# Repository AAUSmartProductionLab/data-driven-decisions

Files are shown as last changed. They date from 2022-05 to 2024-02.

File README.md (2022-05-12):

# IIoT Box Start-up guide

This guide will describe the step-by-step process to set up the IIoT Box on the shopfloor.

## Initial Steps

   1. Power up the box using the USB-A to USB-A cable provided in the box.
   2. Connect to the WiFi Access Point with that has the same name as the IIoT Box (e.g. iiot_box_2).
   3. Once connected, the status of the raspberry pi can be check visiting: `10.3.141.1` in the browser. The credentials are: **username: iiot_case_2** and **password: robotlab**. From the dashboard it can be seen what devices are connected to the IIoT Box this could for example be the sensor boxes. These will appear with the host name ESP followed by a 6 number/letter ID e.g. **ESPBox1** or **ESPBox2**.
   4. If everything is up and running (see: [Troubleshooting](TROUBLESHOOTING.md)) Node-RED can be accessed through port 1880. So go to the address `10.3.141.1:1880` in the browser.
   5. In Node-RED data can be accessed, analyzed and formatted such that it can be used in a dashboard or for storing. For a more in depth guide on Node-RED check the guide here (see: [Node-RED Guide](node-red/README.md)).

---

## Contents of the IIoT Box

The IIoT box contains a Raspberry Pi 3B/3B+ that is used for setting up the access point and for storing the data from the sensor boxes. The IIoT box comes a 7-inch touch display, which can be used for debugging and visualization purposes. The IIoT box also comes with two sensor boxes. These sensor boxes uses a Wemos D1 Mini Pro ESP8266 microcontroller for collection and sending of data from the sensors. The exact sensors and their respective datasheets can be found in the folder [Sensor Descriptions and Datasheets](sensors/README.md).

---

## Usernames and Passwords

| | IIoT_Box_1  | IIoT_Box_2  | IIoT_Box_3  | IIoT_Box_4  |
|---|---|---|---|---|
| Username | pi | pi | pi | pi |
| Password | robotlab | robotlab | robotlab | robotlab |
| SSID(WiFi Name) | iiot_case_1 | iiot_case_2 | iiot_case_3 | iiot_case_4 |
| WiFi Password | robotlab | robotlab | robotlab | robotlab |
| Raspap username | admin | admin | admin | admin |
| Raspap password | robotlab | robotlab | robotlab | robotlab |

---

## More Guides and Descriptions

- [Node-RED Guide](node-red/README.md)
- [Communication and Electrical Diagrams](diagrams/README.md)
- [Sensor Descriptions and Datasheets](sensors/README.md)
- [Troubleshooting](TROUBLESHOOTING.md)
- [Code](code/README.md)

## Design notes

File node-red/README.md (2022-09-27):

# Node-RED Guide

This is a guide on how to use and understand the currently implemented Node-RED flows. This guide will only go through the basics briefly, so it is suggested to watch this YouTube guide to get a better understanding of Node-RED (see: [Video-Guide](https://www.youtube.com/watch?v=3AR432bguOY&ab_channel=OptoVideo)).

## The Basics

Node-RED is a flowbased programming tool developed by IBM and is often times used to interface different programs and APIs with eachother. This feature is very useful, in the context of IoT and IIoT, since there are often many different devices that operate with different programming languages, interfaces and programs. Node-RED can then act as the glue tying all these technologies together. The programs made in Node-RED are known as **flows** and these **flows** consist of **nodes** that are essentially programming blocks that have different functionalities. The **nodes** usually have an input, output or both and can be chained together to give a desired output.

Node-RED is accessed through a webinterface that is usually located on port `1880`. This means that if you type the IP-address of the device, running Node-RED, into the URL field in the browser followed by `:1880` it should open Node-RED. An example of this can be seen in the Figure 1.

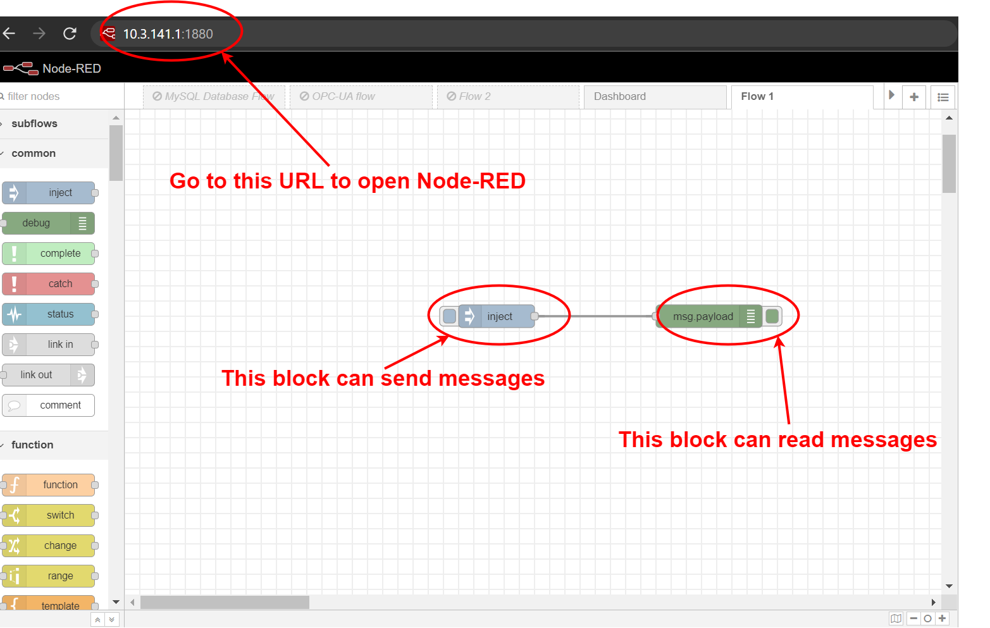
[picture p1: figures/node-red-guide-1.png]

*Figure 1: Node-RED example flow*

Two of the most essential programming blocks can also be seen in the Figure 1. The **inject** node and the **debug** node. The **inject** node is used to send messages, timestamps or to trigger other nodes. The **debug** node is used to read messages from different parts of the flow.

Node-RED has many basic nodes for message manipulation, these nodes can sort, join and split messages. Other nodes are related to connectivity such as MQTT, TCP, UDP and HTTP built in. In the IIoT boxes the primary communication protocol used is MQTT, that is often used together with various IoT devices such as ESP32.

## The IIoT Box Flow

The IIoT Boxes currently has two flows implemented in Node-RED. Firstly, there is a data collection flow that sends the data from the sensors on the ESP Boxes into a localized database in the IIoT Box. Secondly, there is a visualization flow that is used to show an example of a dashboard that can be made from the data stored in the database.

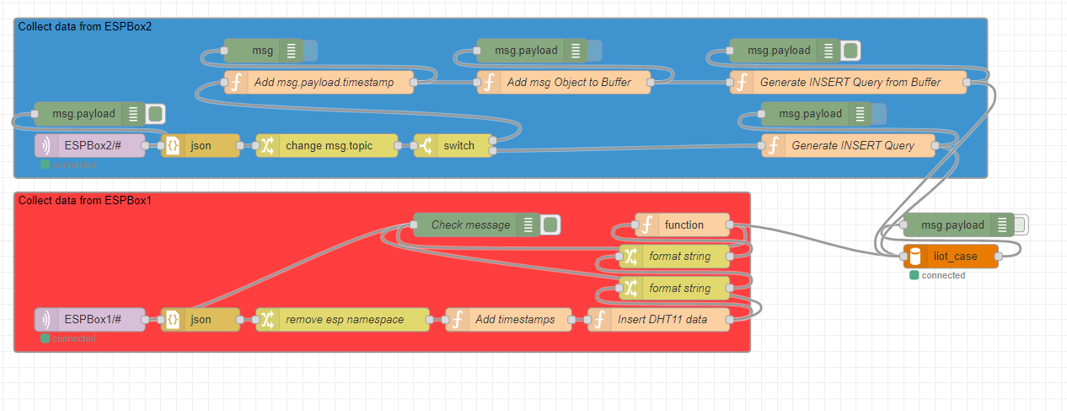
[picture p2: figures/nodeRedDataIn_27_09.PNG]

*Figure 2: The Node-RED Data Insert Flow as of 27/09/2022.*

As shown in Figure 2., there are currently (27/09/2022) two data insert pathways; one for each ESP-box. The ESPBox1 flow concerns the DHT11 data, the ESPBox2 flow concerns the IMU and Line Tracker. The DHT11 sensor document must be parsed and correct timestamps applied, as the ESPs do not have the correct time. The resulting records are then entered into the database. A buffer is implemented for the IMU sensor data, due to the high sample rate of this sensor (50ms). The other ESPBox2 data values are entered into the relevant tables in the database based on their topic (tracker, tracker2, etc.).

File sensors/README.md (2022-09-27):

# Sensors
Several sensor options have been implemented, descriptions of which can be found below. The sensors that have currently (11/07/2022) been 
implemented are:

- Diffuse/Reflective Optosensor
- DHT11
- IMU

### Optosensor
The selected optosensor can be ustilised in either diffuse- or reflective-mode (diffuse-mode is default). In the former implemen-
-tation, the sensor functions as a normally open (NO) contact, and as a normally closed (NC) in the latter. In order to switch
modes, it is necessary to alter the sensing circuit configuration, to reconfigure the Node-RED flows and also to make use of re-
-flective material. It is advised that this reconfiguration be carried out by or in collaboration with the Lab Engineers or an-
-other, qualified person.

##### Code Function
The code for the Optosensor makes use of a state machine to monitor the status of the sensor relative to previous statuses. If no
 object is detected by the sensor, and no object has been previously detected, a '0' status is returned. If an object is then de-
 -tected, a '1' status is returned. If this object remains for a period of time, that is, continues to be detected, then a '2' 
 status is returned. When the object finally ceases to be detected, a '3' status is returned. This modality is inverted when the 
 sensor is configured in reflective-mode. The following table should serve to clarify:
 
| **Condition** | **Previous Condition** | **Diffuse-Mode** | **Reflective-Mode** |
|---|---|---|---|
| No Object | No Object | 0 | 2 |
| Object | No Object | 1 | 3 |
| Object | Object | 2 | 0 |
| No Object | Object | 3 | 1 |

The sensor condition is sampled on a 200ms basis as default, but this time can be successfully reduced to 50ms for fast moving sys-
-tems. Currently (27/09/2022), only 1 and 0 values are sent on to Node-RED. 

### DHT11
The DHT11 sensor is used to sample ambient temperature and humidity in an area. This sensor provides a humidity sensing range of 
20-80% with an accuracy of ±5%, and a temperature sensing range of 0-50°C with an accuracy of ±2°C. The sample rate is max 1Hz. 

##### Code Implementation
The current (11/07/2022) code implementation samples the temperature and humidity every 5 minutes, stores this data as a JSON-document 
on the ESP-box until 6 samples have been collected. This JSON-document is then published to the MQTT topic ESPBox1/DHT11. 

### IMU
The IMU sensor is used to gather acceleration and rotation data. An MPU6050 is currently (27/09/2022) used for this sensor. 

##### Code Implementation
The current (27/09/2022) code implementation samples the IMU data every 50ms and publishes this data immediately to the MQTT topic 
ESPBox2/imu.

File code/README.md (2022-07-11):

# Code
In this directory, the various code pieces that are used by the Raspberry Pi and the ESP-boxes can be found.
The contents of each folder are:

- **cpp:** This folder contains cpp-files for each ESP-box (1 & 2), they have been developed with PlatformIO using the Arduino framework.
           There is also a folder condtaining code for a wiegand-based RFID-reader.
- **node-red:** This folder contains JSON-files for the exported flows from Node-RED running on the Raspberry Pi. The currently hosted
            flows include:
            - Data Input
            - Dashboard
            - Datalog Download
- **python:** This folder contains a python script which governs the display for the Raspberry Pi touch-screen, as well as .png-files for
           this.

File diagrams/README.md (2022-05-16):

# Technical Documentation
Here is the documentation for the IIoT Box and the ESP Boxes

## Electrical Diagrams
Below you can see diagrams of the two ESP Box types. These show the connections between the various components and the requisite 
voltage levels to assist in troubleshooting of the ESP Boxes. 

### ESP Box Type 01
The Type 01 ESP Box has both an RFID reader and DHT11 connected, which are supplied separately via the 5V and 3.3V pins on the ESP.
This type utilises the ESP's built-in DeepSleep functionality, which requires that the RST pin be connected to the D0 pin, in order 
for the ESP to wake-up without external intervention. Below can be seen the electrical diagram for the Type 01 ESP Box.

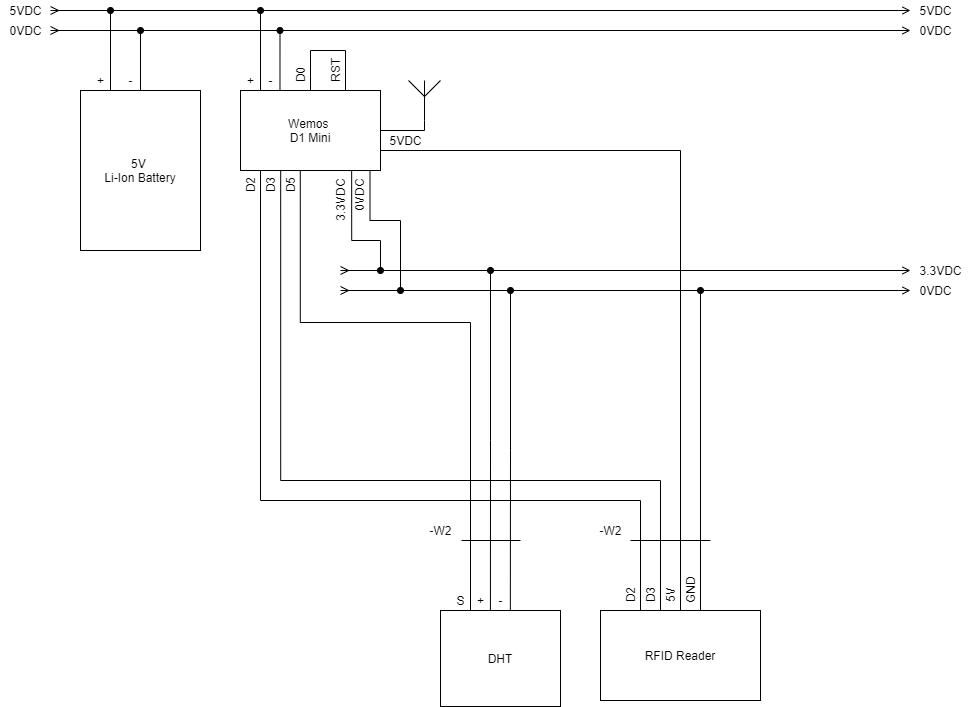
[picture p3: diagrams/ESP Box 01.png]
Electrical Diagram of the ESP Box Type 01


The below table summarises the pin connections for the Type 01:

| ESP Pin | Conductor Colour | Target | Comment |
|---|---|---|---|
| D0 | --- | RST |  Function not currently used |
| Tx | | Tx (RFID)  | |
| Rx | | Rx (RFID)  | |
| 5V | Red | Vcc (RFID) | |
| GND | Black | GND | |
| D5 | Blue | S (DHT11)  | |
| 3.3V | Red | + (DHT11)  | |
| GND | Black | - (DHT11)  | |

### ESP Box Type 02
The Type 02 ESP Box has an IMU and an industrial diffuse/through-beam PNP-type optosensor connected, which are supplied separately 
via the 3.3V and 5V pins on the ESP. The optosensor is supplied 12V via a 5V/12V Boost Regulator. This type does not utilise the 
ESP's built-in DeepSleep functionality. Below can be seen the electrical diagram for the Type 02 ESP Box.

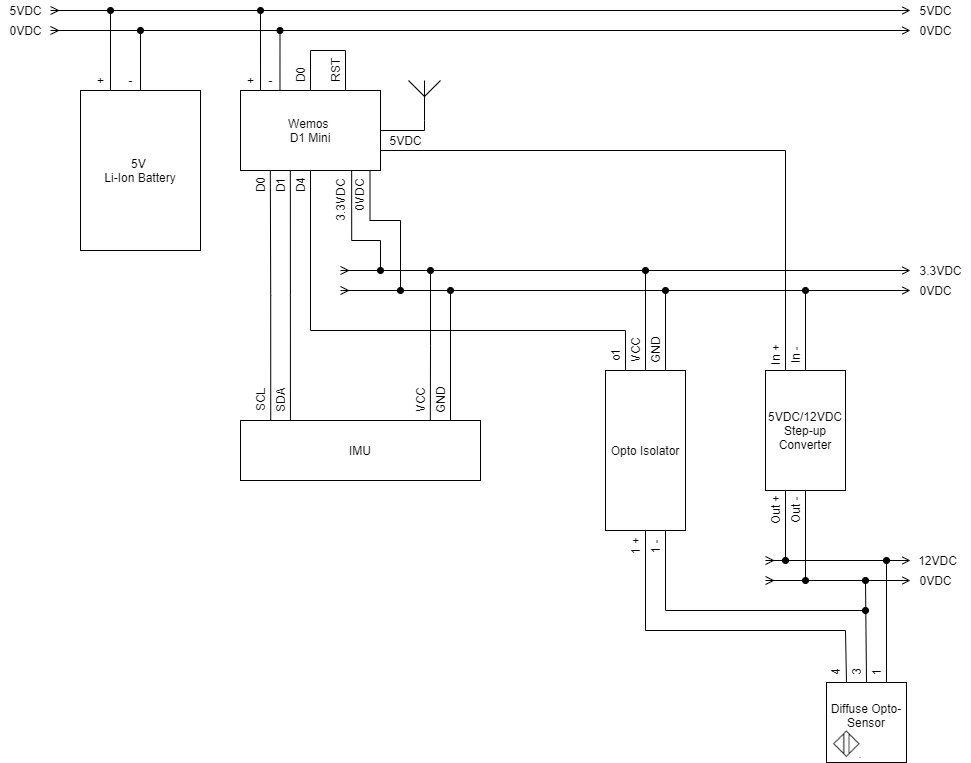
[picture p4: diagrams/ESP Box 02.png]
Electrical Diagram of the ESP Box Type 02


The below table summarises the pin connections for the Type 02:

| ESP Pin | Conductor Colour | Target | Comment |
|---|---|---|---|
| D0 | Green | SCL (IMU) | |
| D1 | Blue | SDA (IMU) | |
| 3.3 | Red | Vcc (IMU) | |
| GND | Black | GND (IMU) | |
| D4 | White | o1 (Optoisolator) | |
| 3.3V | Red | Vcc (Optoisolator) | |
| GND | Black | GND (Optoisolator) | |
| 5V | Red | In+ (5V/12V Step-up) | |
| GND | Black | In- (5V/12V Step-up) | |

Furthermore, the pin connections for the optoisolator board are summmarised below:

| Optoisolator Pin | Conductor Colour | Target | Comment |
|---|---|---|---|
| 1+ | Black | Pin 4 (Optosensor) | |
| 1- | Blue | Pin 3 (Optosensor)/ GND (5V/12V Step-up) | |
| 2+ | Brown | Pin 2 (Optosensor) | Function currently not in use (can be connected) |

Finally, the pin connections for the Boost Regulator are summarised below:

| 5V/12V Step-up Converter Pin | Conductor Colour | Target | Comment |
|---|---|---|---|
| In+ | Red | 5V (ESP) | |
| In- | Black | GND (ESP) | |
| Out+ | White | Pin 1 (Optosensor) | |
| Out- | Blue | Pin 3 (Optosensor)/ 1- (Optoisolator) | |

## Communication Diagrams
The below diagram illustrates the data flow from sensors to user, to assist in troubleshooting data-collection
issues. 

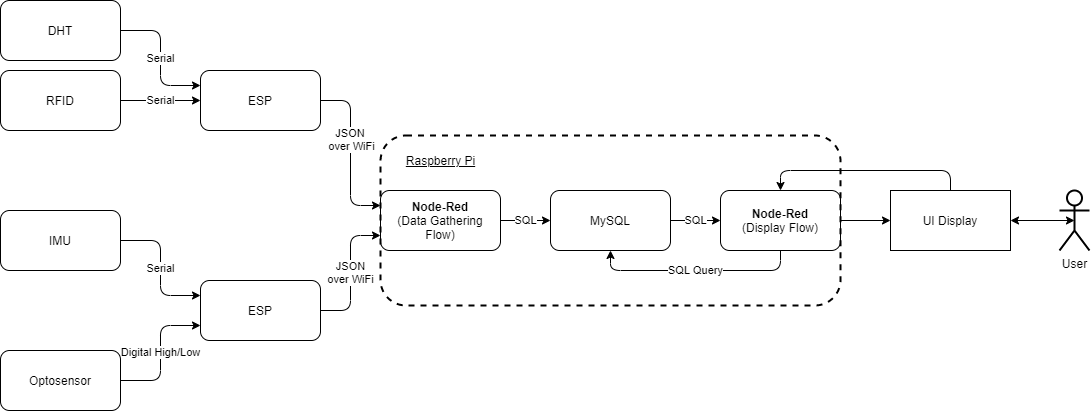
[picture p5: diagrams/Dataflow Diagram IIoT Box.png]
IIoT Box Data Flow


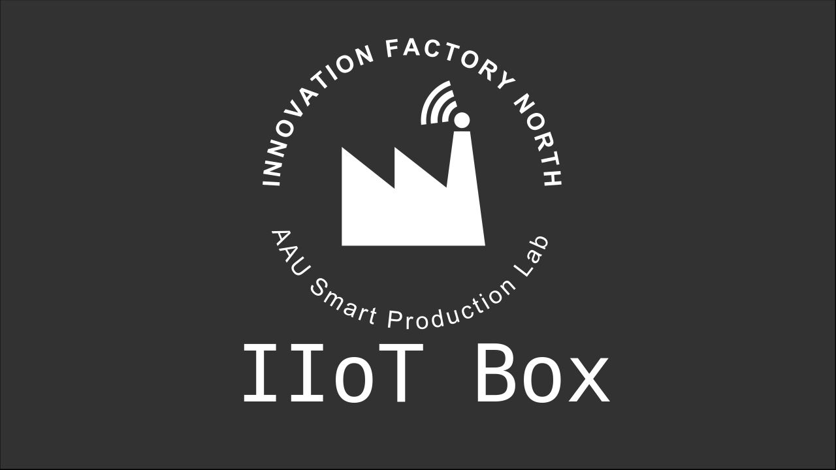
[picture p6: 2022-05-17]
figures/wallpaper_iiotbox.png

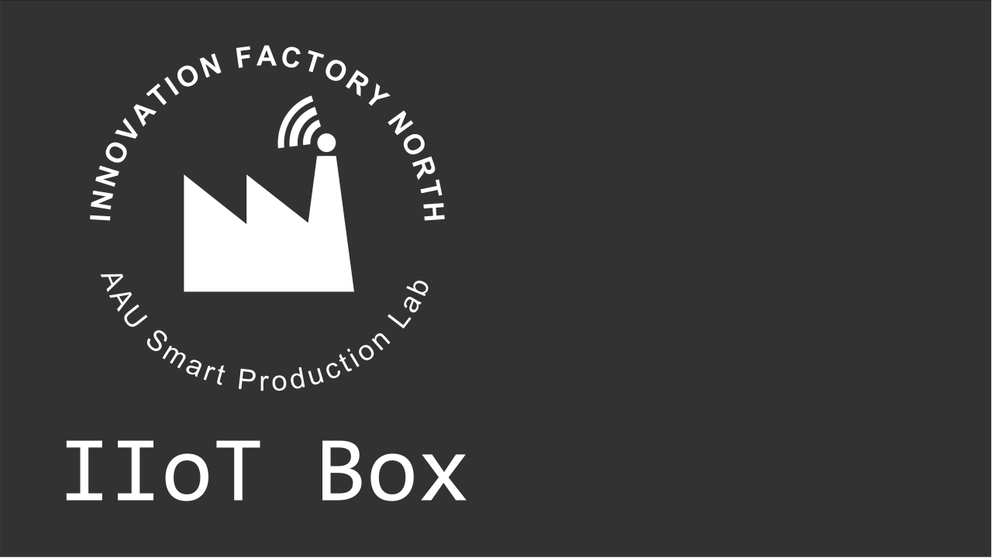
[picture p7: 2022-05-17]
code/python/iiot_box_wallpaper.png

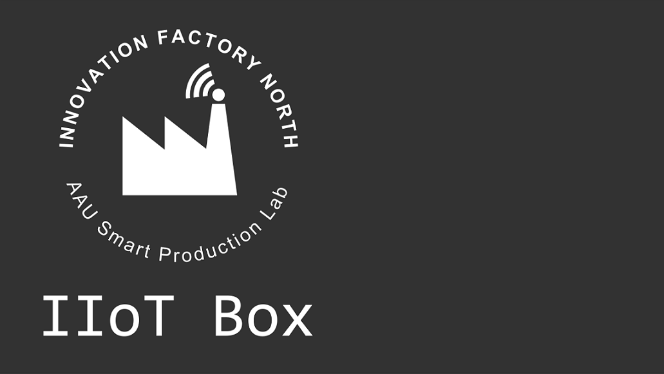
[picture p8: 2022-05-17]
code/python/iiot_box_wallpaper_small.png

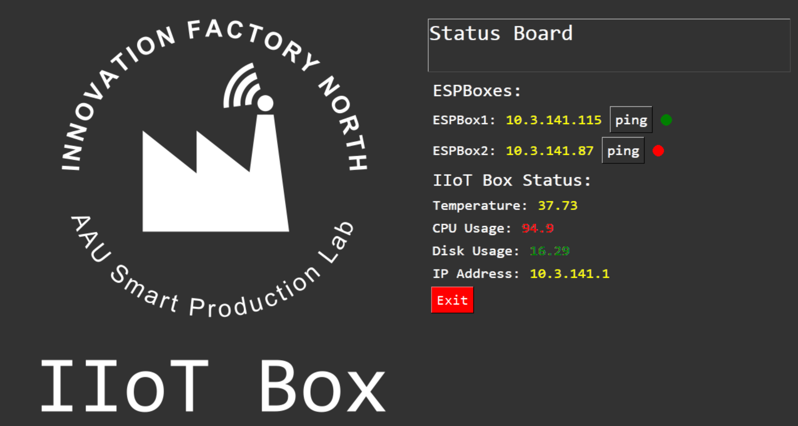
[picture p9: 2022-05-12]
figures/gui-python.png

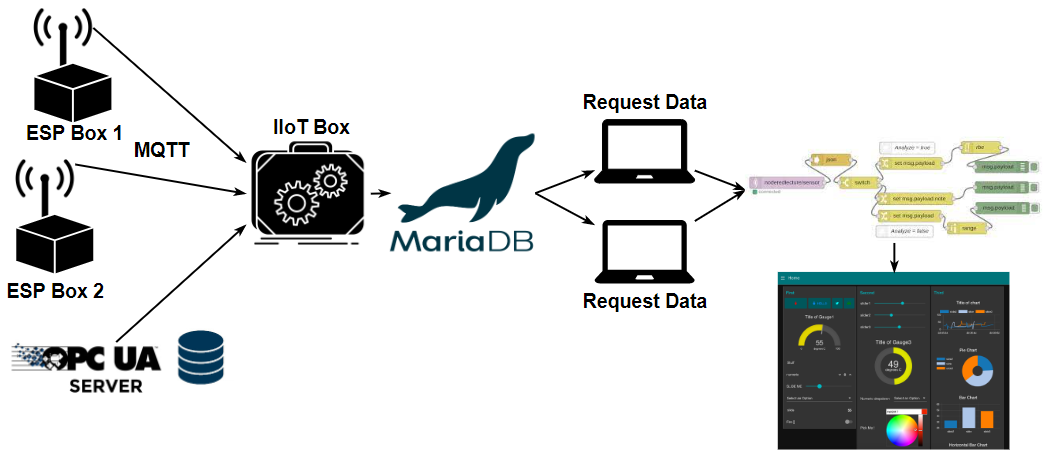
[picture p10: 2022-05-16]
figures/structure_2.png

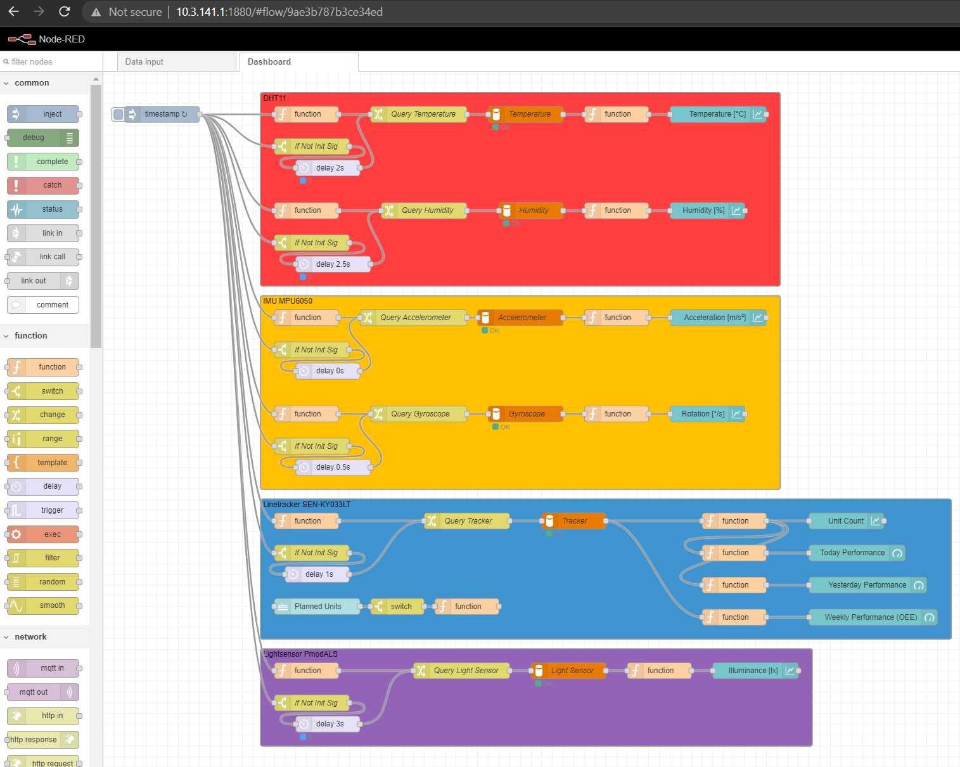
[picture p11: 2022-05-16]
figures/node-red-ui-flow.png

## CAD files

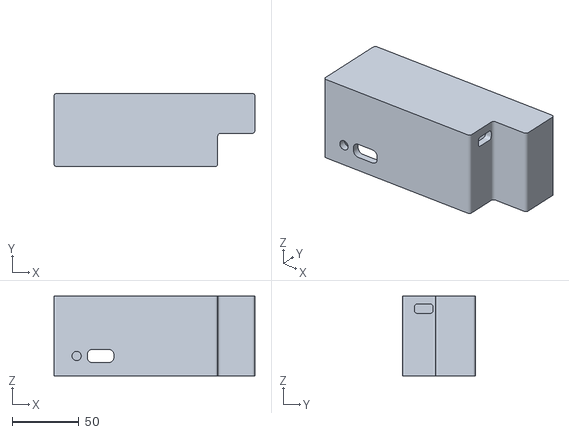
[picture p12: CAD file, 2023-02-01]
3D_models/espcase.stl
151.0 x 55.0 x 60.0

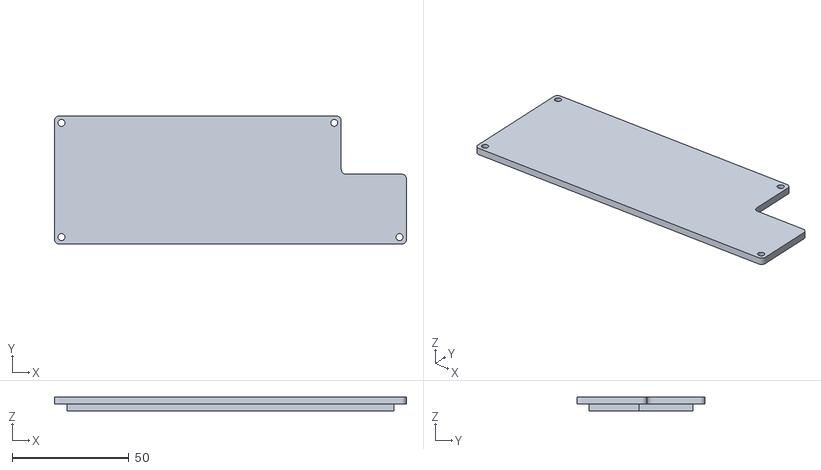
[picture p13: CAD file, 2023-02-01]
3D_models/espcase_lid.stl
151.0 x 55.0 x 6.00

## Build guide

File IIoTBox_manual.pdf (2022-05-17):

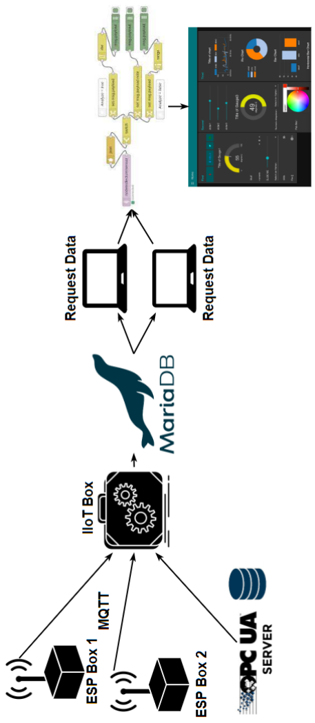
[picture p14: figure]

Contact Information

Name: Martin Bieber Jensen E-mail: martinbj@mp.aau.dk Phone: +4522666973
Address: Fibigerstræde 14, Room 34

Name: Raphael Peter Harrow-Hodgkinson E-mail: rphh@mp.aau.dk
Phone: +4591741380
Address: Fibigerstræde 14, Room 34

Name: Helge Glinvad Grøn
E-mail: helgegg@mp.aau.dk
Phone: +4599407663
Address: Pontoppidanstræde 103

Links

Link to Documentation:
https://github.com/AAUSmartProductionLab/datadriven-decisions/

Link to IFN Homepage:
https://www.ifn.aau.dk/

The link to the documentation can also be found

scanning the QR code here: | | | |

# Industrial Internet of Things Box Manual

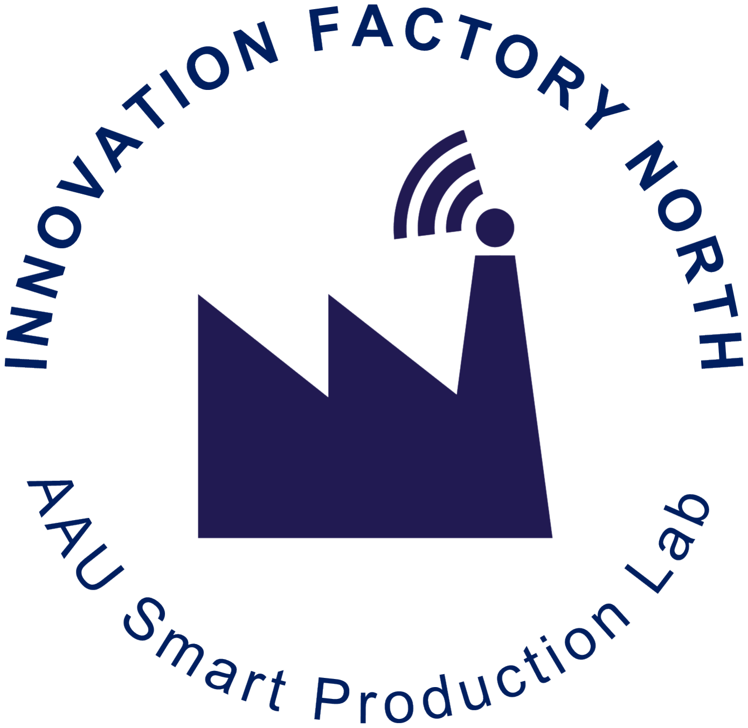
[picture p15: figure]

IFN Demonstrator 7

Martin B. Jensen
Raphael P. Hodgkinson

Overview

The IIoT Box is created as a part of an Innovation Factory North(IFN) Demonstrator. The general purpose of the box is to help Small and Medium sized Enterprises(SMEs) try out different sensor solutions in their production, to see what data creates value in their companies.

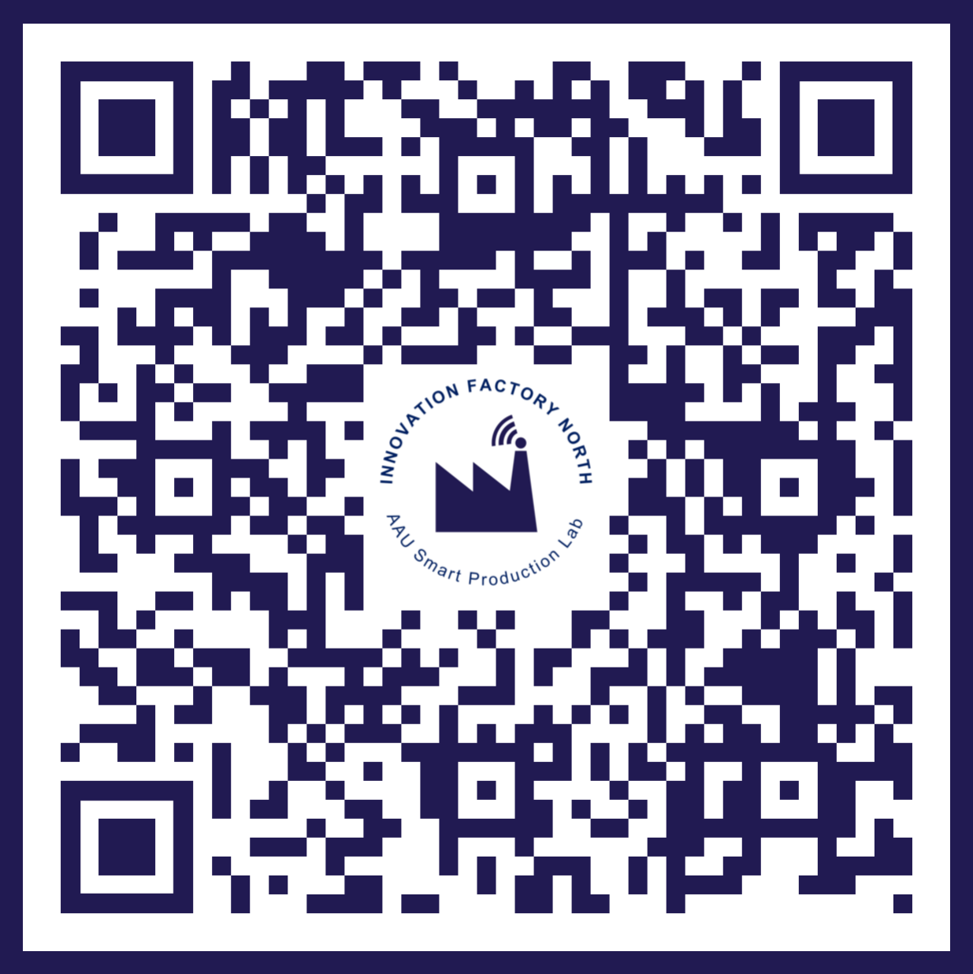
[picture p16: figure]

This manual will contain some of the essential information in order to get the IIoT Box up and running as well as links and references to more in depth documentation and guides etc.

Getting Started

This is a short getting started guide with the steps to get the IIoT Box up and running. The steps are listed below:

Power up the box using the barrel plug power cable 1.

provided in the box. (Wait a few minutes for the Box

to properly boot up).

Once the IIoT Box is booted up, connect to the WiFi 2.

Access Point with that has the same name as the IIoT

Box (e.g. iiot_box_2 or iiot_box_3).

Once connected, the status of the raspberry pi can be 3.

URL in the browser. 10.3.141.1 checked by visiting:

and password: admin The credentials are: username:

. robotlab

From the dashboard it can be seen what devices are 4.

connected to the IIoT Box this could for example be the sensor boxes. These will appear with the host name ESPBox1 or ESPBox2. If these two are connected the IIoT Box should be receiving data from

ESP Boxes.

If everything is up and running Node-RED can be 5.

accessed through port 1880. So go to the address in the browser. 10.3.141.1:1880

In Node-RED data can be accessed, analyzed and for- 6.

matted such that it can be used in a dashboard or for storing. For a more in depth guide on Node-RED check the documentation found in the links in this

manual.

The data is sent through MQTT from the ESP Boxes 7.

and the data can be checked through the debug win-

dow in Node-RED.

The IIoT Box also has the capabilities of collecting 8.

data from an OPC-UA server. However this requires some integration at the specific site in order to work.

The ethernet port on the box can be used for this

# purpose |

Contents of the box

A list of the contents of the box is listed. The list shows the content of both the IIoT Box and the ESP Boxes that are contained within the IIoT Box.

IIoT Box: •

7-inch Touchscreen Joy-it RB-LCD7.2 ×1 o

Raspberry Pi 3B/3B+ ×1 o

Goobay USB-C Cable (For charging battery) ×1 o

Goobay Micro USB (For programming the × 1 o

ESP Boxes)

ESP Box 1: ×1 o

Wemos D1 Mini Pro ESP8266 ×1 *

Carlo Gavazzi Photoelectric sensor ×1 *

PH18CND10PAM1SA

Joy-it MPU6050 IMU ×1 *

Cellularline Powerbank 3000 mAh ×1 *

Micro USB (Power from battery to × 1 *

ESP8266)

ESP Box 2: ×1 o

Wemos D1 Mini Pro ESP8266 ×1 *

Joy-it SEN-KY015TF DHT 11 ×1 *

Seeed Studio Grove-125KHz RFID Reader ×1 *

Cellularline Powerbank 3000 mAh ×1 *

Micro USB (Power from battery to × 1 *

# ESP8266) |

Usernames and Passwords

A table, of the commonly used usernames and passwords that is used to connect to the various interfaces of the

IIoT Box, can be found in Table 1.

Password Username Credentials

robotlab pi Linux

robotlab IIoT_case_n* WiFi Credentials robotlab admin Raspap Dashboard

Table 1: Table of usernames and passwords (* n is the

number of the box)

Miscellaneous Information

The IIoT Box has some additional features and informa-

tion provided here.

The IIoT Box can be connected directly to the internet and this creates options for storing the data in the cloud for wider access to the data.

The ESP Boxes can also be expanded with additional sensors, however this requires some programming of the

ESP8266 within the ESP Box.

The range between the IIoT Box and the ESP Boxes is approximately 15 meters. This can range can be increased in the future with the addition of a long range WiFi mo-

dem and antenna.

The ESP Boxes has a battery life of approximately +48 hours for the ESP Box 1 and 36 hours for the ESP Box

2.

A simplified architecture of the IIoT Box solution can be found on the back of this manual.

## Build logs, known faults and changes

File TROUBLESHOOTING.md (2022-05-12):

# Troubleshooting

This page can be used to help get the box up and running if there are any problems with it.

## Trouble Connecting to IIoT Box

f

___

## Trouble Connecting IIoT Box to ESP Boxes

- ping
- reset on button
- Check power or connect to power

___

## Issues starting up Node-RED

___

## Invalid data to database

- Check sensor connection
- Serial monitor
- serial comms can be on pin rx + tx when uploading code

___

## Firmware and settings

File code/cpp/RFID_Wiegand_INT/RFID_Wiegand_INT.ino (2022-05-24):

//  RFID_Wiegand_INT.pde  to read card ID number from the RFID with
// wiegand interface.
//  see http://www.seeedstudio.com/depot/ for details on 125K RFID module

//  Copyright (c) 2010 seeed technology inc.
//  Author: Icing Chang
//  Version: september 2, 2010
//
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
byte RFIDcardNum[4];
byte evenBit = 0;
byte oddBit = 0;
byte isData0Low = 0;
byte isData1Low = 0;
int recvBitCount = 0;
byte isCardReadOver = 0;

void setup()
{
  Serial.begin(9600);
  attachInterrupt(0, ISRreceiveData0, FALLING );  //data0/tx is connected to pin 2, which results in INT 0
  attachInterrupt(1, ISRreceiveData1, FALLING );  //data1/rx is connected to pin 3, which results in INT 1

}

void loop()
{
  //read card number bit
  if(isData0Low||isData1Low){
    if(1 == recvBitCount){//even bit
      evenBit = (1-isData0Low)&isData1Low;
    }
    else if( recvBitCount >= 26){//odd bit
      oddBit = (1-isData0Low)&isData1Low;
      isCardReadOver = 1;
      delay(10);
    }
    else{
      //only if isData1Low = 1, card bit could be 1
      RFIDcardNum[2-(recvBitCount-2)/8] |= (isData1Low << (7-(recvBitCount-2)%8));
    }
    //reset data0 and data1
    isData0Low = 0;
    isData1Low = 0;
  }

  //print the card id number
  if(isCardReadOver){
    if(checkParity()){
    //Serial.println();
    //Serial.print(RFIDcardNum[2],HEX);//High byte
    //Serial.print(RFIDcardNum[1],HEX);//Midle byte
    //Serial.println(RFIDcardNum[0],HEX);//Low byte
      Serial.println(*((long *)RFIDcardNum));
    }
    resetData();
  }

}

byte checkParity(){
  int i = 0;
  int evenCount = 0;
  int oddCount = 0;
  for(i = 0; i < 8; i++){
    if(RFIDcardNum[2]&(0x80>>i)){
      evenCount++;
    }
  }
  for(i = 0; i < 4; i++){
    if(RFIDcardNum[1]&(0x80>>i)){
      evenCount++;
    }
  }
  for(i = 4; i < 8; i++){
    if(RFIDcardNum[1]&(0x80>>i)){
      oddCount++;
    }
  }
  for(i = 0; i < 8; i++){
    if(RFIDcardNum[0]&(0x80>>i)){
      oddCount++;
    }
  }
  
  if(evenCount%2 == evenBit && oddCount%2 != oddBit){
    return 1;
  }
  else{
    return 0;
  }
}
void resetData(){
  RFIDcardNum[0] = 0;
  RFIDcardNum[1] = 0;
  RFIDcardNum[2] = 0;
  RFIDcardNum[3] = 0;
  evenBit = 0;
  oddBit = 0;
  recvBitCount = 0;
  isData0Low = 0;
  isData1Low = 0;
  isCardReadOver = 0;
}
// handle interrupt0
void ISRreceiveData0(){
  recvBitCount++;
  isData0Low = 1;
}

// handle interrupt1
void ISRreceiveData1(){
  recvBitCount++;
  isData1Low = 1;
}

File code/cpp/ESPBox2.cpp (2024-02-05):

//Libraries
#include <Arduino.h>
#include <ESP8266WiFi.h>
#include "PubSubClient.h"
#include <Adafruit_MPU6050.h>
#include <Adafruit_Sensor.h>
#include <Adafruit_SSD1306.h>
#include "SPI.h"
#include <ArduinoJson.h>
#include <Wire.h>

// Digital pin for IR 
#define IRPIN D0 // Pin for IR dectector
// Digital pin for lightsensor
#define CS D8 // Assignment of the CS pin

//Network parameters and MQTT server IP
char ssid[] = "iiot_case_4"; //iiot_case_1, iiot_case_2, iiot_case_3, iiot_case_4
const char* password =  "robotlab"; //the code for all the WiFis
const char* mqtt_server = "10.3.141.1"; //IP addr for all the cases

//Variables
byte intensity = 0; //Stores sensor value for the light sensor
int detect = 0; //1 or 0 depending on if something is in the way
int flag = 1; // Flag is used to check if something moved in front of irsensor and left again
int status = 0; //Status for linetracker 0 = object has moved, 1 = object detected, 2 = object is still there, 3 = no object detected
unsigned long currentMillis = 0;
unsigned long startMillis = 0;
unsigned long period = 2000;

//Define the name of the ESP
String espName = "ESPBox2";

//MQTT
WiFiClient espClient;
PubSubClient client(espClient);

//IMU Class instance
Adafruit_MPU6050 mpu;

/********************************************************************** NETWORK FUNCTIONS ***************************************************************************/

// connect to network function
void connectNetwork(){
  delay(10);
  pinMode(13, OUTPUT); 
  Serial.begin(115200);

  WiFi.hostname(espName.c_str());
  WiFi.begin(ssid, password);
  WiFi.mode(WIFI_STA);
 
  while (WiFi.status() != WL_CONNECTED) {
    delay(500);
    Serial.println(WiFi.status());
  }

  if (!mpu.begin()) {
    Serial.println("Sensor init failed");
    while (1)
      yield();
  }

  Serial.println(WiFi.localIP());
  Serial.println("Connected to the WiFi network");
}

//Attempt to reconnect to MQTT server if the connection is lost
void reconnect() {
  // Loop until we're reconnected
  while (!client.connected()) {
    Serial.print("Attempting MQTT connection...");
    // Create a random client ID
    String clientId = "ESP8266Client-";
    clientId += String(random(0xffff), HEX);
    // Attempt to connect
    if (client.connect(clientId.c_str())) {
      Serial.println("connected");
      // Once connected, publish an announcement...
      client.publish("outTopic", "hello world");
      // ... and resubscribe
      client.subscribe("inTopic");
    } else {
      Serial.print("failed, rc=");
      Serial.print(client.state());
      Serial.println(" try again in 5 seconds");
      // Wait 5 seconds before retrying
      delay(5000);
    }
  }
}

/********************************************************************** SENSOR FUNCTIONS ***************************************************************************/
void imu(){
  sensors_event_t a, g, temp;
  mpu.getEvent(&a, &g, &temp);
  
  String jsonString;
  DynamicJsonDocument doc(1024);

  doc["sensor"] = "IMU";
  doc["timestamp"]   = "time";

  doc["acceleration"][0] = a.acceleration.x;
  doc["acceleration"][1] = a.acceleration.y;
  doc["acceleration"][2] = a.acceleration.z;

  doc["gyroscope"][0] = g.gyro.x;
  doc["gyroscope"][1] = g.gyro.y;
  doc["gyroscope"][2] = g.gyro.z;

  serializeJson(doc, jsonString);
  Serial.println(jsonString);
  String namePub = espName + "/imu";

  client.publish(namePub.c_str(), jsonString.c_str());
}

void lineTracker(){
    detect = digitalRead(IRPIN);
    if (detect == 0 && flag == 0){
      flag = 1;
      status = 0;
      Serial.println("Object has moved on!");
    }
    else if (detect == 1 && flag == 1){
      flag = 0;
      status = 1;
      Serial.println("Object has been detected!");
    }
    else if (detect == 1 && flag == 0){
      status = 2;
     Serial.println("Object is still here!");
    }
    else if (detect == 0 && flag == 1){
      status = 3;
      Serial.println("There is no object!");
    }
    String namePub = espName + "/tracker";

    String jsonString;
    DynamicJsonDocument doc(1024);

    doc["sensor"] = "LineTracker";
    doc["timestamp"] = "time";
    doc["status"] = status;

    serializeJson(doc, jsonString);

    Serial.println(jsonString);

    client.publish(namePub.c_str(), jsonString.c_str());
}

void lightSensor(){
  digitalWrite(CS, LOW); // activation of CS line
  intensity = SPI.transfer(0) << 3; // Aquisition of first 5 bits of data without leading zeros
  intensity |= (SPI.transfer(0) >> 4); //Aquisition of last 3 bits of data and appending
  digitalWrite(CS, HIGH);
  String namePub = espName + "/light";
  
  String jsonString;
  DynamicJsonDocument doc(1024);

  doc["sensor"] = "LightSensor";
  doc["timestamp"] = "time";
  doc["intensity"] = float(intensity);

  serializeJson(doc, jsonString);

  Serial.println(jsonString);

  client.publish(namePub.c_str(), jsonString.c_str());

  delay(200);
}

/********************************************************************** SETUP AND LOOP FUNCTIONS ***************************************************************************/
void setup() {
  connectNetwork();

  SPI.begin(); // initialization of SPI port
  SPI.setDataMode(SPI_MODE0); // configuration of SPI communication in mode 0
  SPI.setClockDivider(SPI_CLOCK_DIV16); // configuration of clock at 1MHz


  pinMode(CS, OUTPUT); //configure pin connected to chip select as output
  pinMode(IRPIN, INPUT); //read the digital input from the linetracker sensor

  client.setServer(mqtt_server, 1883);
  startMillis = millis();
  }

void loop() {
  if (!client.connected()) {
    reconnect();
  }

  client.loop();

  lineTracker();

  delay(500);

}

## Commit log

2022-06-14 Flow for DataLog download
2023-02-01 Add files via upload
    Added 3D models of the small ESP boxes
    [espcase.stl, espcase_lid.stl]
2023-03-15 Create iiot_lecture.json
    Added flow for iiot_lecture
2023-03-15 Update iiot_lecture.json
    Updated Flows
